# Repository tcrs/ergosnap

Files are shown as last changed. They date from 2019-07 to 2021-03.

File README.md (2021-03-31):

# ErgoSnap Keyboard

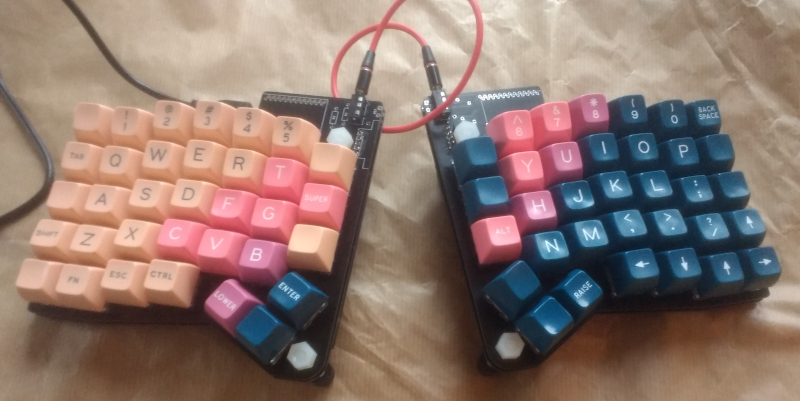
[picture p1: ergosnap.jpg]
ErgoSnap


WARNING. This is rev1.1, which works fine but has a few issues:

 - The silkscreen for the ProMicro outline is incorrect for the USB-up placement
 - USB cable only just plugs into the ProMicro on the left half (plug shroud is
   against the edge of the PCB below the ProMicro)
 - SDA & SCL are the wrong way around on the 5pin header for the Pimoroni
   trackball breakout, so that doesn't work without some jumper wires...

[ErgoDash][1] layout with [Mitosis][2] style PCB construction, reversible ProMicro
chin from [Ergo42][3].

 - Removed all the wiring for backlight/underlight LEDs
 - Uses through-switch diode holes
 - M6 mouting holes on the "inside" board edges for tenting
 - 5 pin connector for [trackball module][4] (no software yet...)

[1]: https://github.com/omkbd/ErgoDash
[2]: https://github.com/reversebias/mitosis-hardware
[3]: https://github.com/Biacco42/Ergo42
[4]: https://shop.pimoroni.com/products/trackball-breakout

## Fabrication

I got my PCBS made at [JLCPCB][5]. No issues.

[5]: https://jlcpcb.com/

## BOM

 - 4 x PCBs
 - 68 x Keyswitches (Cherry MX or compatible)
 - 68 x Diodes (1N4148)
 - 2 x ProMicro + header pins 
 - 2 x TRRS jacks (PJ-320A [aliexpress](https://www.aliexpress.com/item/32825553898.html))
 - 1 x TRRS cable
 - 2 x 4k7 Ohm resistors (I2C pullups)
 - 2 x 5pin headers
 - 4 x M6 nylon screw thread + nuts (for tenting, optional)
 - Some sticky-backed neoprene tape (for padding/non-slip on the bottom of the
   board)

## Build

See [build guide](build_guide/).

## Software

[QMK](https://qmk.fm/). ErgoSnap uses exactly the same matrix as the ErgoDash,
so just build an ErgoDash layout (using the `LAYOUT_3key_1us` layout type).

For an example see my [`ergodash-isolike` layout](https://github.com/tcrs/qmk_firmware/tree/ergosnap-isolike).

Example make command:

	make ergodash/rev1:isolike:avrdude

## License

ErgoDash & Ergo42 are MIT, Mitosis is GPLv3. So this work as a whole is GPLv3.

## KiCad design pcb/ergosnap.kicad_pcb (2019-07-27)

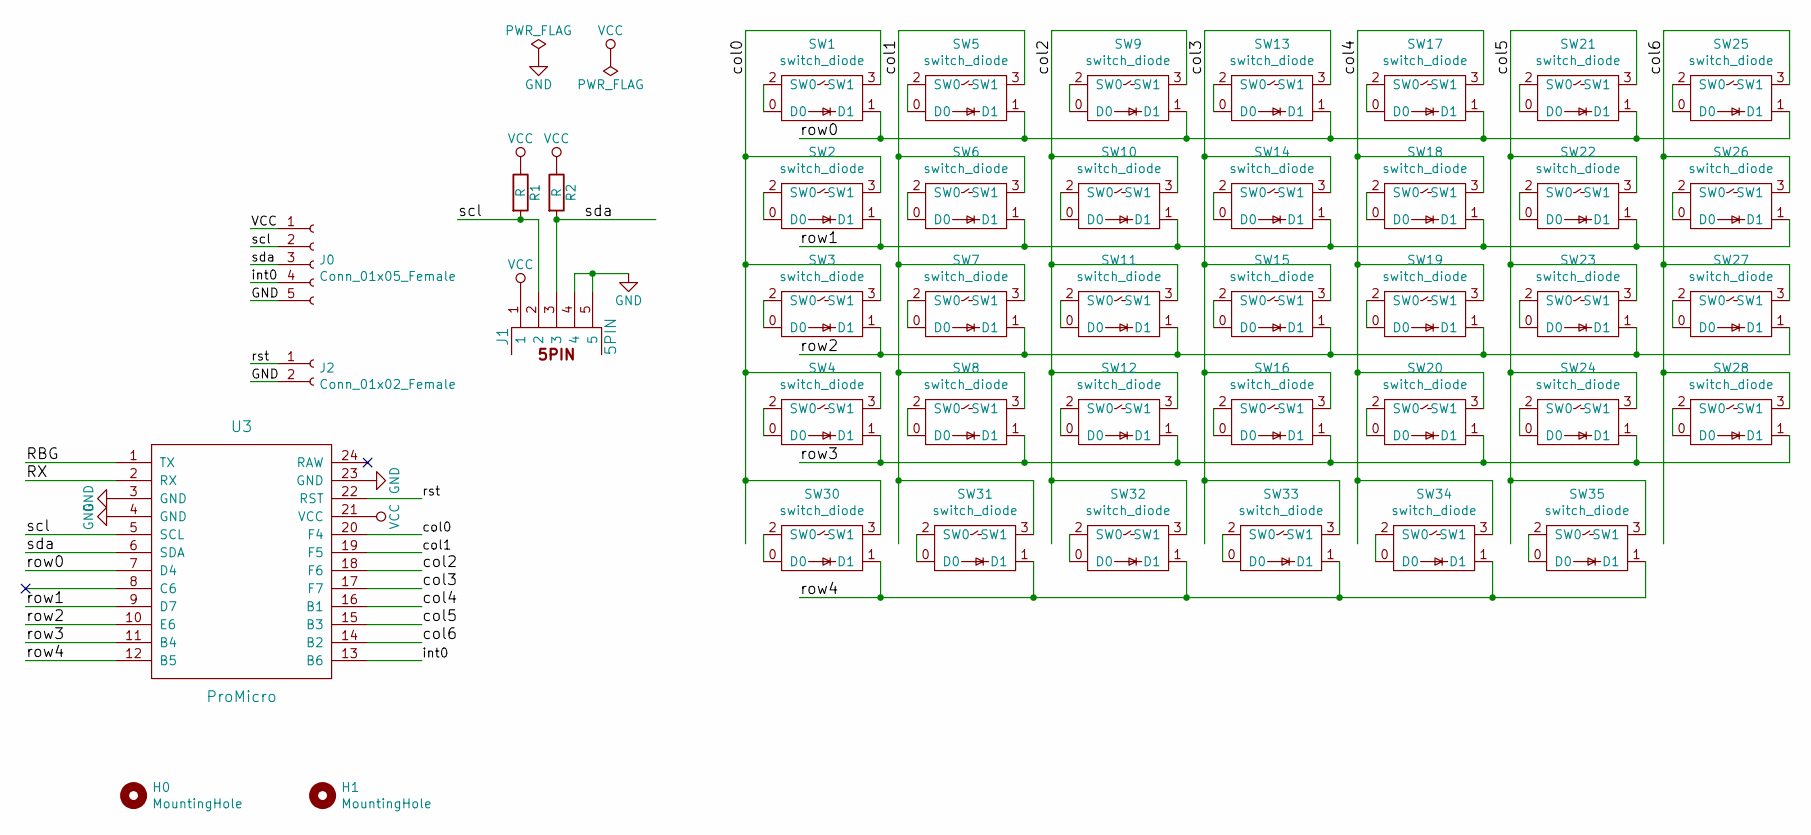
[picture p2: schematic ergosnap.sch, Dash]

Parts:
H0, H1: MountingHole; MountingHole_6.4mm_M6
J0: Conn_01x05_Female; pimoroni_trackball
J1: 5PIN; trrs_jack
J2: Conn_01x02_Female; SolderWirePad_1x02_P3.81mm_Drill0.8mm
R1, R2: R; R_Axial_DIN0207_L6.3mm_D2.5mm_P10.16mm_Horizontal
SW1, SW2, SW3, SW4, SW5, SW6, SW7, SW8, SW9, SW10, SW11, SW12, SW13, SW14, SW15, SW16, SW17, SW18, SW19, SW20, SW21, SW22, SW23, SW24, SW25, SW26, SW27, SW28, SW30, SW31, SW32, SW33, SW34, SW35: switch_diode; cherry_mx_diode_snapout
U3: ProMicro; ProMicroReversible

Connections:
/RBG: U3.1 (TX)
/RX: U3.2 (RX)
/col0: SW1.3 (SW1), SW2.3 (SW1), SW3.3 (SW1), SW4.3 (SW1), SW30.3 (SW1), U3.20 (F4)
/col1: SW5.3 (SW1), SW6.3 (SW1), SW7.3 (SW1), SW8.3 (SW1), SW31.3 (SW1), U3.19 (F5)
/col2: SW9.3 (SW1), SW10.3 (SW1), SW11.3 (SW1), SW12.3 (SW1), SW32.3 (SW1), U3.18 (F6)
/col3: SW13.3 (SW1), SW14.3 (SW1), SW15.3 (SW1), SW16.3 (SW1), SW33.3 (SW1), U3.17 (F7)
/col4: SW17.3 (SW1), SW18.3 (SW1), SW19.3 (SW1), SW20.3 (SW1), SW34.3 (SW1), U3.16 (B1)
/col5: SW21.3 (SW1), SW22.3 (SW1), SW23.3 (SW1), SW24.3 (SW1), SW35.3 (SW1), U3.15 (B3)
/col6: SW25.3 (SW1), SW26.3 (SW1), SW27.3 (SW1), SW28.3 (SW1), U3.14 (B2)
/int0: J0.4, U3.13 (B6)
/row0: SW1.1 (D1), SW5.1 (D1), SW9.1 (D1), SW13.1 (D1), SW17.1 (D1), SW21.1 (D1), SW25.1 (D1), U3.7 (D4)
/row1: SW2.1 (D1), SW6.1 (D1), SW10.1 (D1), SW14.1 (D1), SW18.1 (D1), SW22.1 (D1), SW26.1 (D1), U3.9 (D7)
/row2: SW3.1 (D1), SW7.1 (D1), SW11.1 (D1), SW15.1 (D1), SW19.1 (D1), SW23.1 (D1), SW27.1 (D1), U3.10 (E6)
/row3: SW4.1 (D1), SW8.1 (D1), SW12.1 (D1), SW16.1 (D1), SW20.1 (D1), SW24.1 (D1), SW28.1 (D1), U3.11 (B4)
/row4: SW30.1 (D1), SW31.1 (D1), SW32.1 (D1), SW33.1 (D1), SW34.1 (D1), SW35.1 (D1), U3.12 (B5)
/rst: J2.1, U3.22 (RST)
/scl: J0.2, J1.2, R1.2, U3.5 (SCL)
/sda: J0.3, J1.3, R2.2, U3.6 (SDA)
GND: J0.5, J1.4, J1.5, J2.2, U3.3 (GND), U3.4 (GND), U3.23 (GND)
unnamed: SW1.0 (D0), SW1.2 (SW0)
unnamed: SW2.0 (D0), SW2.2 (SW0)
unnamed: SW3.0 (D0), SW3.2 (SW0)
unnamed: SW4.0 (D0), SW4.2 (SW0)
unnamed: SW5.0 (D0), SW5.2 (SW0)
unnamed: SW6.0 (D0), SW6.2 (SW0)
unnamed: SW7.0 (D0), SW7.2 (SW0)
unnamed: SW8.0 (D0), SW8.2 (SW0)
unnamed: SW9.0 (D0), SW9.2 (SW0)
unnamed: SW10.0 (D0), SW10.2 (SW0)
unnamed: SW11.0 (D0), SW11.2 (SW0)
unnamed: SW12.0 (D0), SW12.2 (SW0)
unnamed: SW13.0 (D0), SW13.2 (SW0)
unnamed: SW14.0 (D0), SW14.2 (SW0)
unnamed: SW15.0 (D0), SW15.2 (SW0)
unnamed: SW16.0 (D0), SW16.2 (SW0)
unnamed: SW17.0 (D0), SW17.2 (SW0)
unnamed: SW18.0 (D0), SW18.2 (SW0)
unnamed: SW19.0 (D0), SW19.2 (SW0)
unnamed: SW20.0 (D0), SW20.2 (SW0)
unnamed: SW21.0 (D0), SW21.2 (SW0)
unnamed: SW22.0 (D0), SW22.2 (SW0)
unnamed: SW23.0 (D0), SW23.2 (SW0)
unnamed: SW24.0 (D0), SW24.2 (SW0)
unnamed: SW25.0 (D0), SW25.2 (SW0)
unnamed: SW26.0 (D0), SW26.2 (SW0)
unnamed: SW27.0 (D0), SW27.2 (SW0)
unnamed: SW28.0 (D0), SW28.2 (SW0)
unnamed: SW30.0 (D0), SW30.2 (SW0)
unnamed: SW31.0 (D0), SW31.2 (SW0)
unnamed: SW32.0 (D0), SW32.2 (SW0)
unnamed: SW33.0 (D0), SW33.2 (SW0)
unnamed: SW34.0 (D0), SW34.2 (SW0)
unnamed: SW35.0 (D0), SW35.2 (SW0)
VCC: J0.1, J1.1, R1.1, R2.1, U3.21 (VCC)

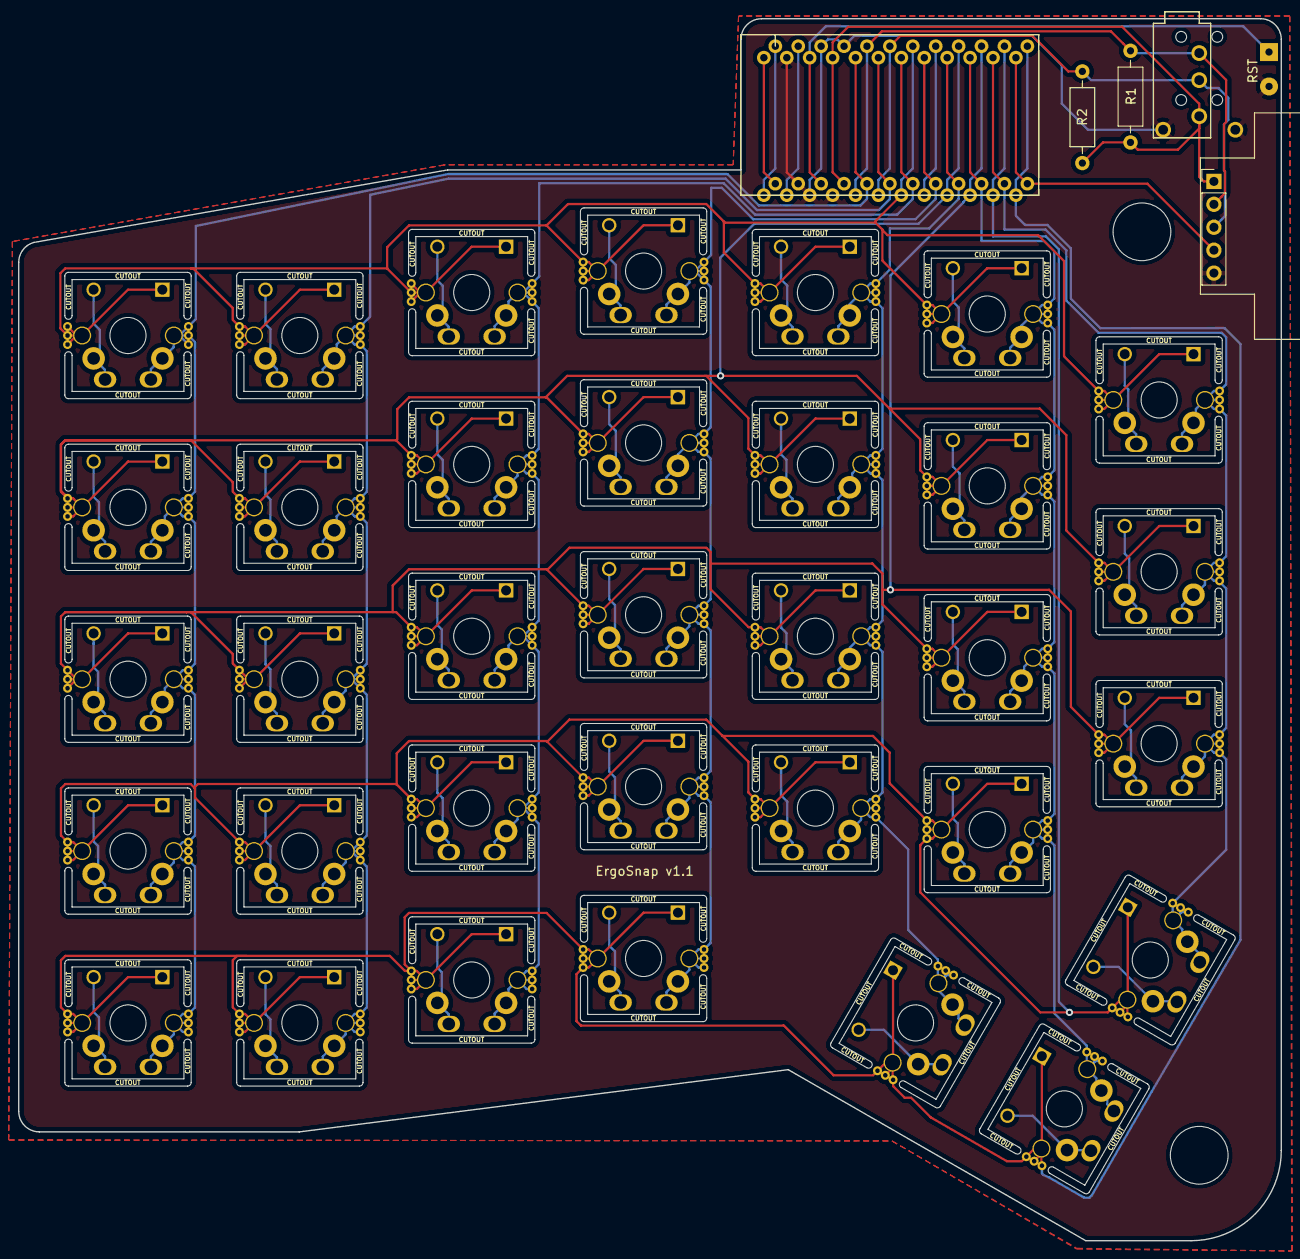
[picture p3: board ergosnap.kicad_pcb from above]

Board: 2 copper layers, 140.0 x 135.5 mm, 42 parts (0 on the bottom side), 52 nets.

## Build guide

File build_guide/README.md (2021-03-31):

# Build Guide

Each half of the keyboard is made up of two boards, bottom and top.

The pictures in this guide are all of the *right* hand half, everything is
mirrored on the left half.

## Bottom board

Solder headers onto the ProMicro. I snip the headers into chunks of 4 before
soldering as you'll want to pull the plastic spacer off after soldering and that
makes it easier.

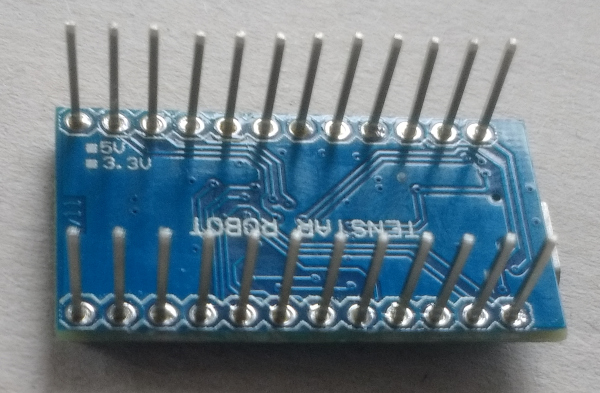
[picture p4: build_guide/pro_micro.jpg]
ProMicro with soldered headers


Now solder the ProMicro onto the board. This will be your bottom board. The
silkscreen is incorrect - don't align the ProMicro with the outline. Check the
RST pin is connected to the reset header on the board edge and the GND pins are
in the right place. Make sure you get the ProMicro flush against the board as
the space it fits into between the two boards is quite tight.

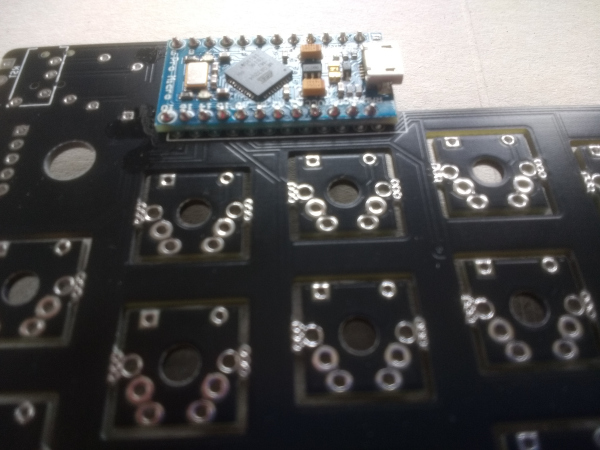
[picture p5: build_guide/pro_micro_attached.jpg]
ProMicro soldered onto board

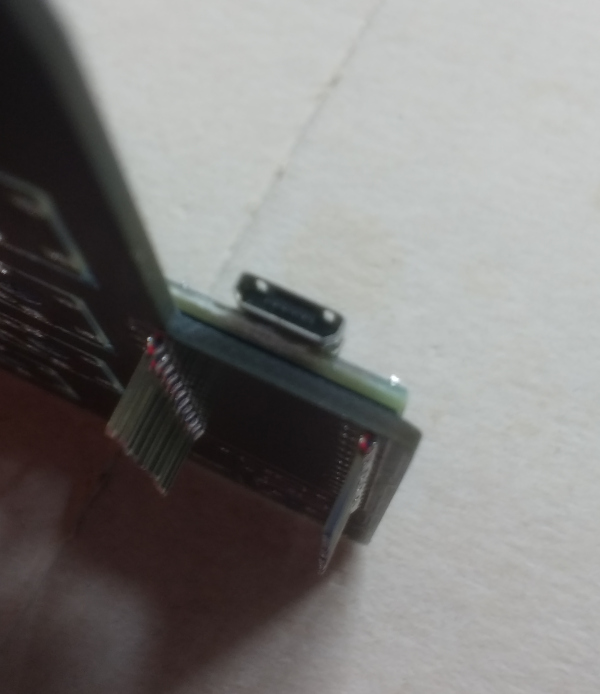
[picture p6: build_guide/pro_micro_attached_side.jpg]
ProMicro soldered onto board, side view


Solder a 5 pin header on

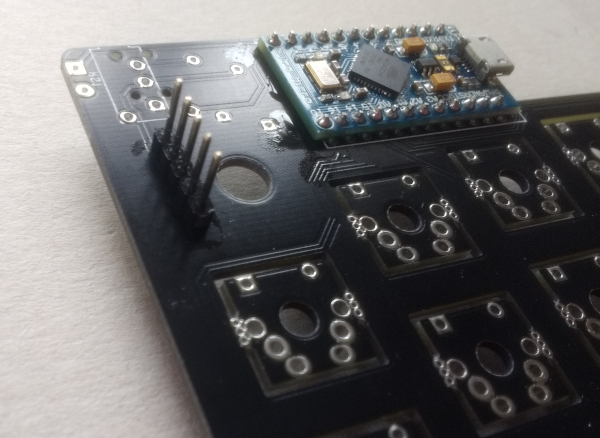
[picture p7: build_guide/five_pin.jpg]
Five pin header soldered onto board


On **one half only**, solder on the two i2c pullup resistors behind the
ProMicro.

### For switches without diode holes (e.g. normal Cherry MX)

Solder diodes onto the *bottom* of the PCB. Make sure the leg from the side of
the diode with a black stripe goes to the square pad! All the black stripes
should be towards the "inside" edge of the board (that's the left side for the
right half and the right for the left half). Use flush cutters to trim the legs
(sticking out of the top of the board) as flush as possible - make sure that a
switch can sit flat on top of the soldered legs.

## Top Board

Snap out all the keyswitch footprints.

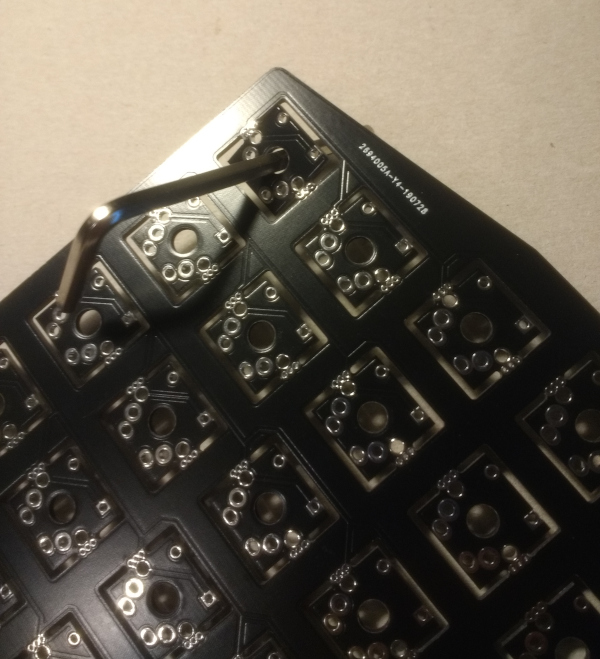
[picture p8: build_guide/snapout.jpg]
Snapping out keyswitch footprints


Get a screwdriver or something (I've used an allen key here) that fits in the
center keyswitch mounting hole and rock it back and forward until the footprint
detaches. Repeat for them all. Once they are all out go round and clean up the
snapped-off sections a bit.

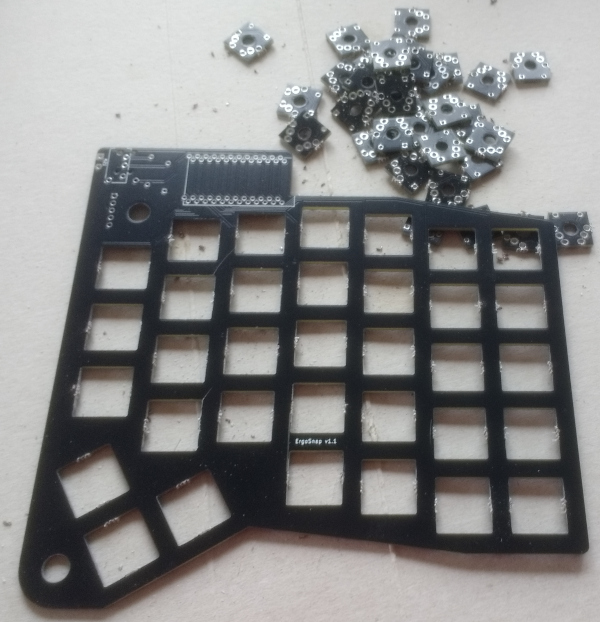
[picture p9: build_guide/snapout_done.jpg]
All footprints snapped out and cleaned up


Solder on the TRRS jack.

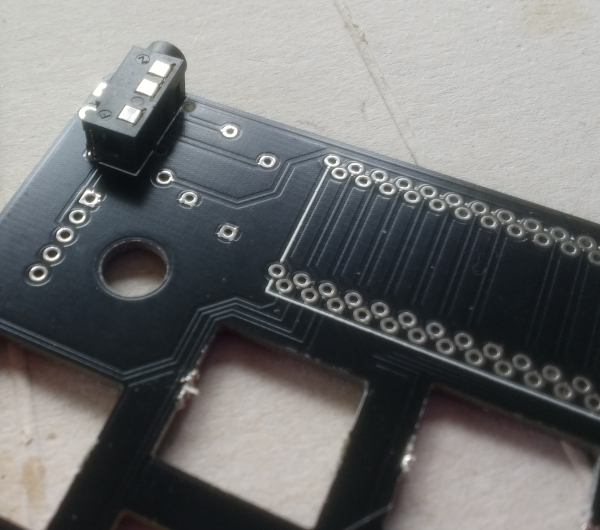
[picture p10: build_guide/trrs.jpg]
TRRS jack soldered on


Solder on the keyswitches. I started by aligning four in the corners to make
sure everything was lined up.

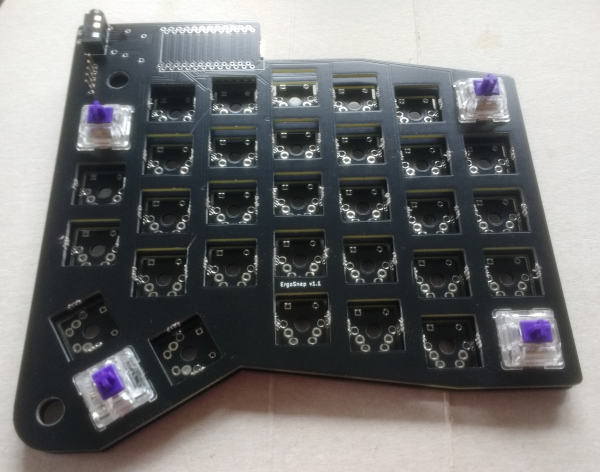
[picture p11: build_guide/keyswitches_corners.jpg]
Keyswitches soldered on in the corners


Solder the five pin header onto the top board (this passes the power and I2C
pins through to the TRRS jack).

### For switches with diode holes (e.g. Zealios)

Place the diodes, legs go through the holes in the top of the switches and out
of the bottom next to the switch pins. Make sure the leg from the side of the
diode with a black stripe goes to the square pad! All the black stripes should
be towards the "inside" edge of the board (that's the left side for the right
half and the right for the left half). Solder in the diodes, making sure they
are pulled through reasonably tightly so that the diode sits against the switch
and isn't sticking up.

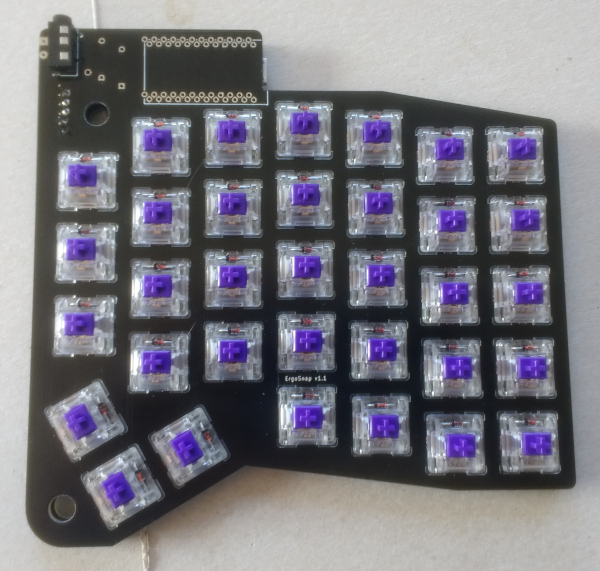
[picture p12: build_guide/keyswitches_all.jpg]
Keyswitches and diodes soldered on


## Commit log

2019-07-08 Initial version of PCB
    [ergosnap.kicad_pcb, ergosnap.sch]
2019-07-08 Fiddle with trackball header
    [ergosnap.kicad_pcb]
2019-07-09 Add cutout on silkscreen on slots
    [ergosnap.kicad_pcb]
2019-07-09 Generated gerber files
    [ergosnap-B_Cu.gbr, ergosnap-B_Mask.gbr, ergosnap-B_SilkS.gbr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]
2019-07-10 Actually add drill layer to gerber zip (oops)
2019-07-11 Remove alignment mark on Edge.Cuts layer
    Looks like JCLPCB treat this as part of the board
    [ergosnap-B_Cu.gbr, ergosnap-B_Mask.gbr, ergosnap-B_SilkS.gbr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]
2019-07-12 Increase clearance between cutouts and board edge
    Went for around 5mm, JLCPCB want a minimum of 3mm
    Also rounded off the bottom right corner a bit more
    [ergosnap-B_Cu.gbr, ergosnap-B_Mask.gbr, ergosnap-B_SilkS.gbr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]
2019-07-13 Tweak board outline a bit
    Right hand edge now a single line and actually straight
    [ergosnap-B_Cu.gbr, ergosnap-B_Mask.gbr, ergosnap-B_SilkS.gbr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]
2019-07-25 Move diode holes to correct spacing
    Incorrectly measured this, diodes don't fit!
    [ergosnap.kicad_pcb]
2019-07-27 Rev1.1 final (?)
    - Added reset header
    - Reshaped the bottom of the board slightly
    - Moved most of the component references off the silkscreen
    - Marked pin 1 in ProMicro footprint
    - Added 2 switch traces missed in last update
    [ergosnap-B_Cu.gbr, ergosnap-B_Mask.gbr, ergosnap-B_SilkS.gbr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]
2019-08-17 Add basic BOM & SW sections to readme
2021-03-31 Explain support for keyswitches without diode holes
    Can solder the diodes onto the bottom of the board to support switches
    without diode holes (e.g. Cherry MX).
